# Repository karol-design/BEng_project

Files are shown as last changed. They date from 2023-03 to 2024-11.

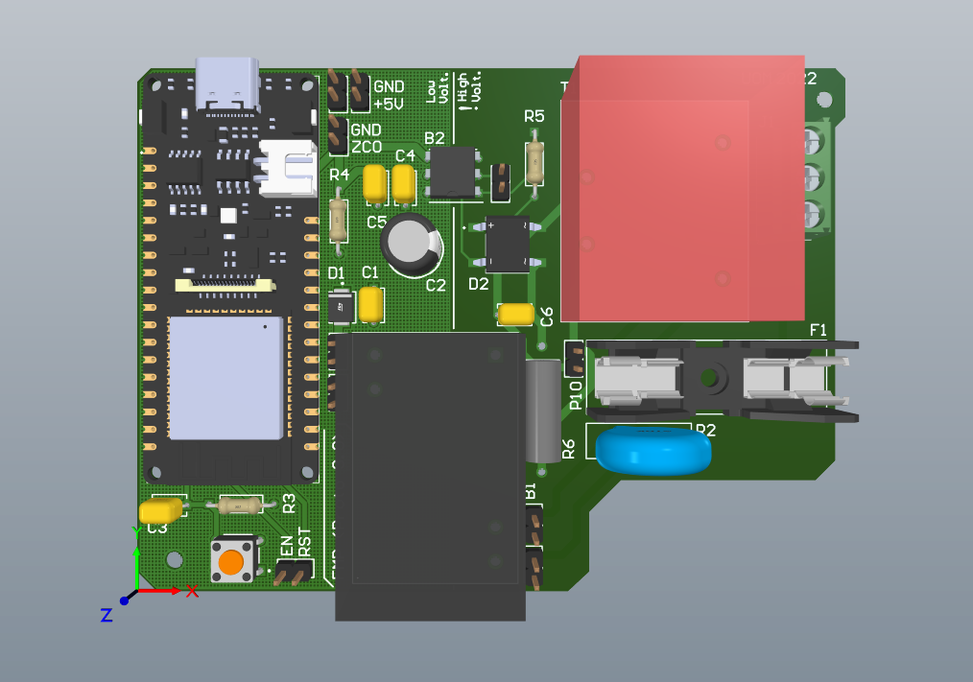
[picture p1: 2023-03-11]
board-design/FMP_Proto_4.0/Project Outputs for FMP_Proto_4.0/Proto4.0_3D.png

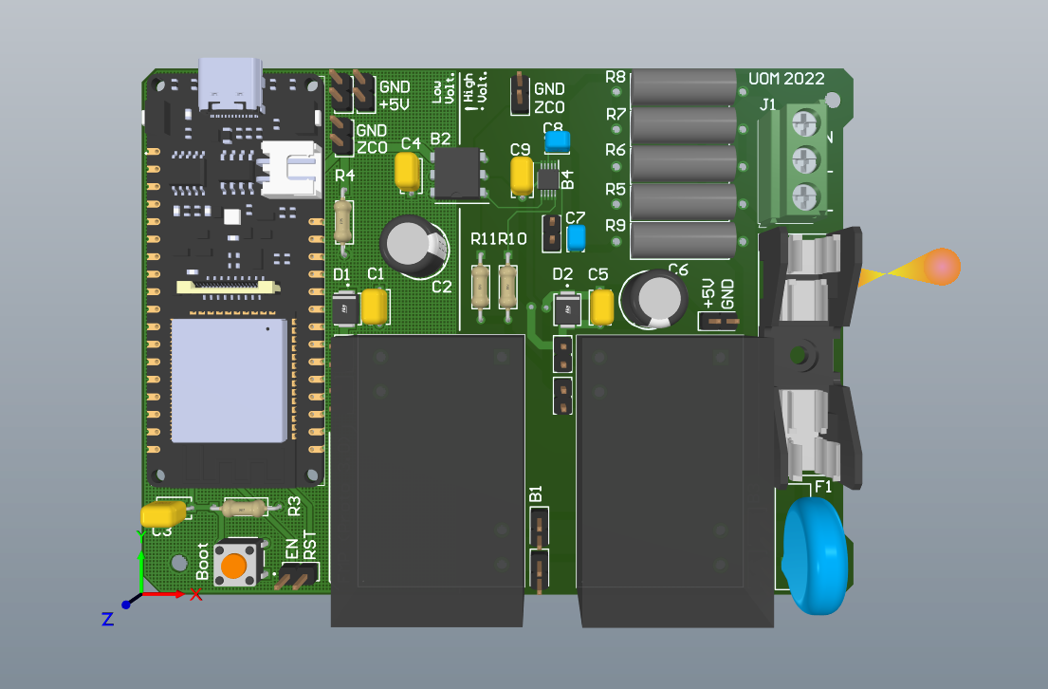
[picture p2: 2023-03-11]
board-design/FMP_Proto_3.0/Project Outputs for FMP_Proto_3.0/Proto3.0_3D.png

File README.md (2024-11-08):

HertzNet Logo
## HertzNet | High-accuracy Wireless Mains Frequency Measurement System
BEng 3rd Year Individual Project | University of Manchester

### CI Workflow results

 

## About 
HertzNet is a system for measuring mains (utility/line) frequency in different locations and aggregating collected data.

The aim of this project was to design and build a system for real-time mains frequency monitoring,
consisting of a low-price plug-in devices with wireless communication, capable of measuring and
uploading accurate and high-resolution frequency data and a web interface which aggregates that
data and makes it searchable and well-presented. 

## Directories
- /board-design - Altium Design files, i.e. Schematics, PCB layouts and 3D models of current and previous versions of the HertzNet Measurement Unit
- /board-fw - Firmware for ESP32-WROOM-32E MCU which controls the HertzNet Measurement Unit
- /cloud-scripts - MATLAB script(s) for the HeartzNet's ThingsSpeak channel

## Contributing (Firmware)
Commit to the main only the code that compile without any warnings or errors.
To test, compile or flash the code use ESP-IDF 4.4

### HertzNet Proto 3.0
3D Model for Proto 3.0

<center>Figure 1. - 3D Model for Proto 3.0</center>

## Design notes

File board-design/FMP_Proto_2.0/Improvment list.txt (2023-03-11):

Potential improvements circuit/PCB:
- more SMD components (resistors, capacitors, chips) and hence smaller size, better decoupling, closer to professional devices
- full galvanic isolation between mains voltage and logic sides (separate 5V power supply for the MAX IC)
- better physical isolation / differentiation between mains voltage and logic sides
- Live/Neutral swap protection, ideally in a form of a transformer with a bridge providing additional galvanic isolation and protection (very important, especially for EU plugs, which in most or all of the cases are unpolarised and there is no definite standard for the placement of Live / Neutral)
- Replace DFRobot ESP32 dev board with own circuit and ESP32 chip
- Replace the Earting wire (acts as a great victim of crosstalk from Live-Neutral loop, both capacitive and inductive crosstalk, if not connected to earth)
- Add Live, Neutral, Boot SW, Project name etc. labels on the PCB

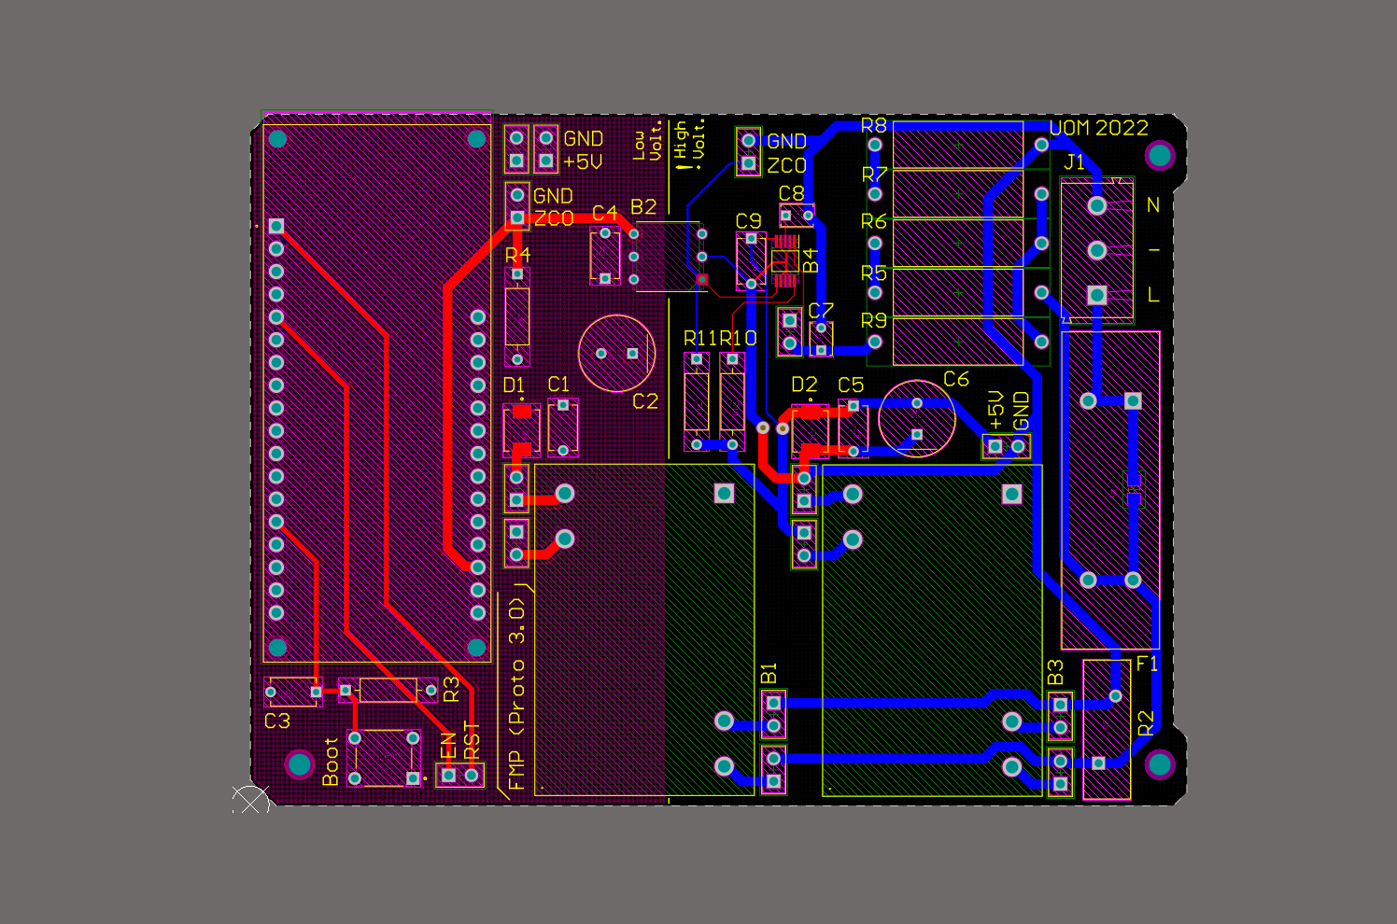
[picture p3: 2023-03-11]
board-design/FMP_Proto_3.0/Project Outputs for FMP_Proto_3.0/Proto3.0_PCB.png

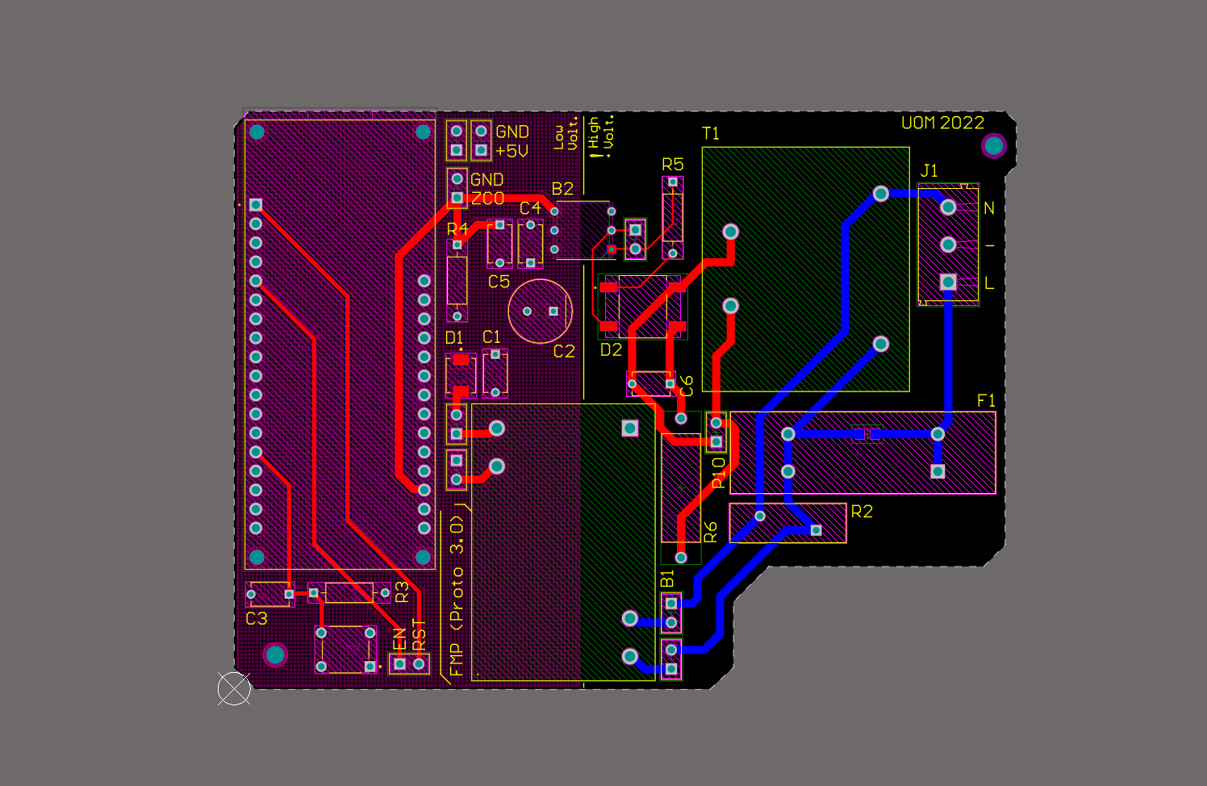
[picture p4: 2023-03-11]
board-design/FMP_Proto_4.0/Project Outputs for FMP_Proto_4.0/Proto4.0_PCB.png

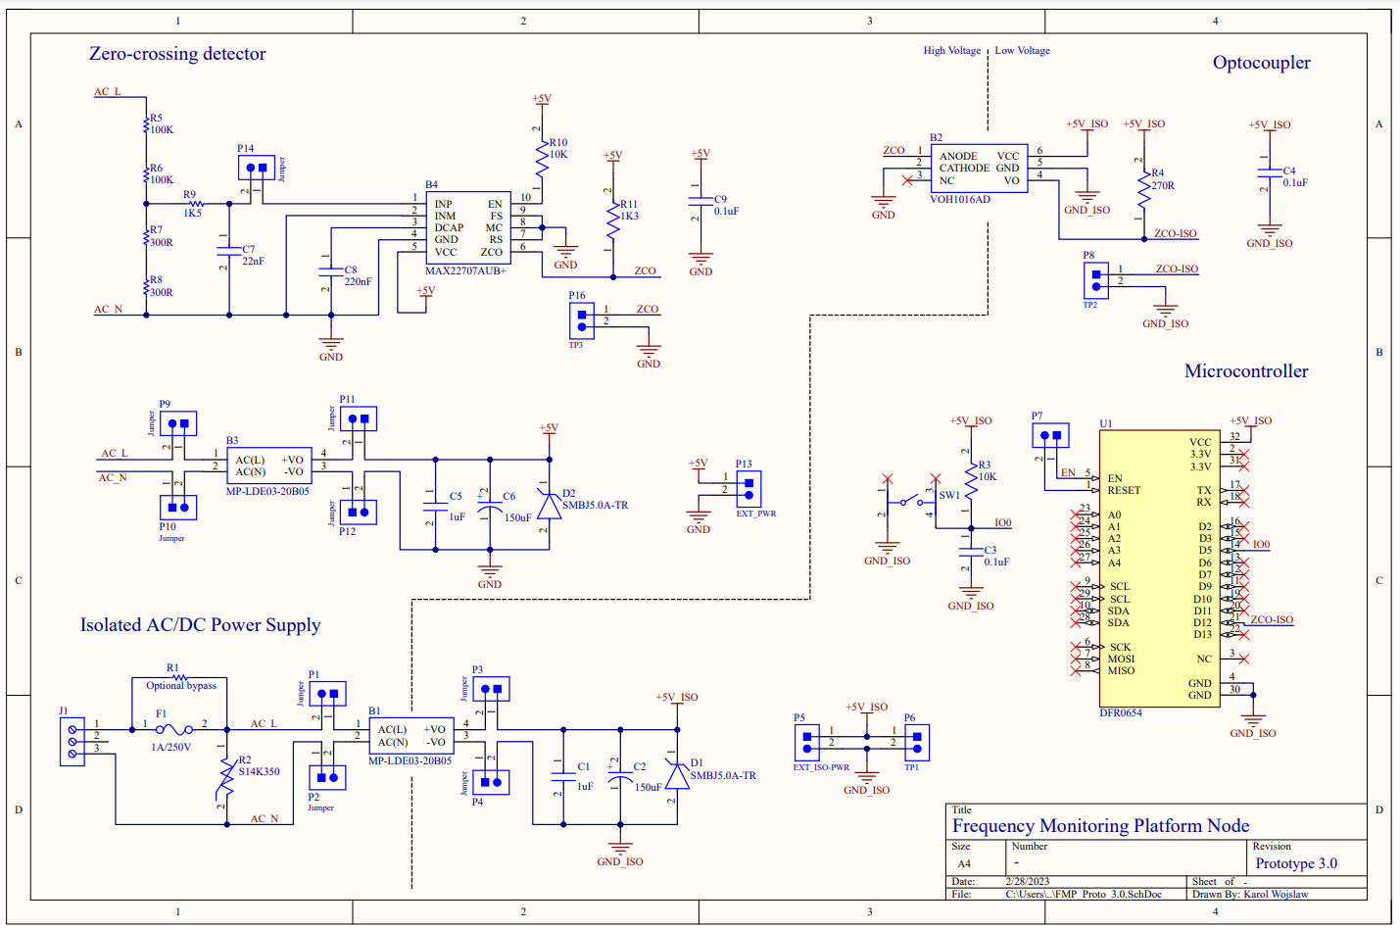
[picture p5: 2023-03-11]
board-design/FMP_Proto_3.0/Project Outputs for FMP_Proto_3.0/Proto3.0_SCH.png

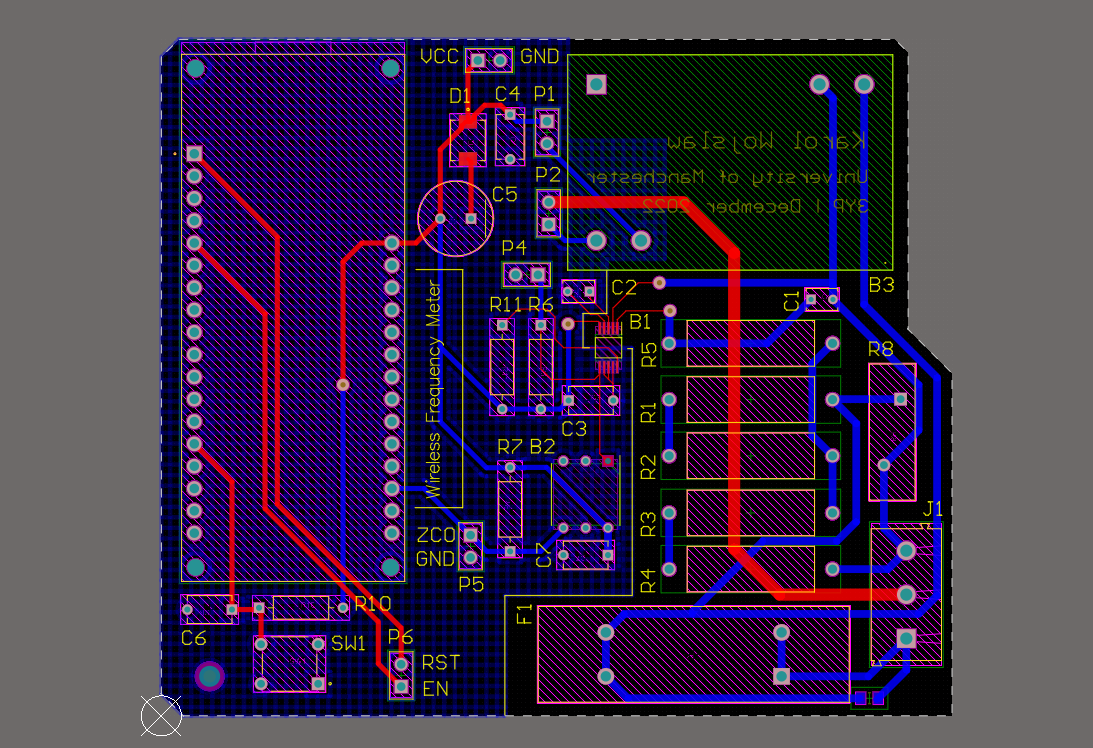
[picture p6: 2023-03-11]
board-design/FMP_Proto_2.0/Project Outputs for MFMS_Node/Proto2.0_PCB.png

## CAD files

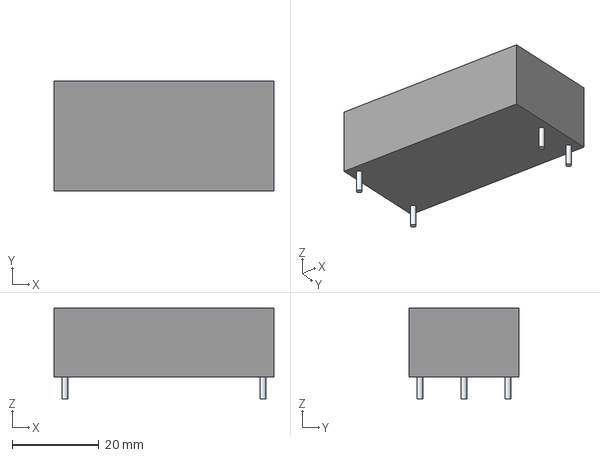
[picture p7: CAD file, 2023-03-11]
board-design/FMP_Proto_2.0/ECAD_models/MP-LDE03-20B05/MP-LDE06-20B24.stp
50.8 x 25.4 x 21.0 mm
Leads

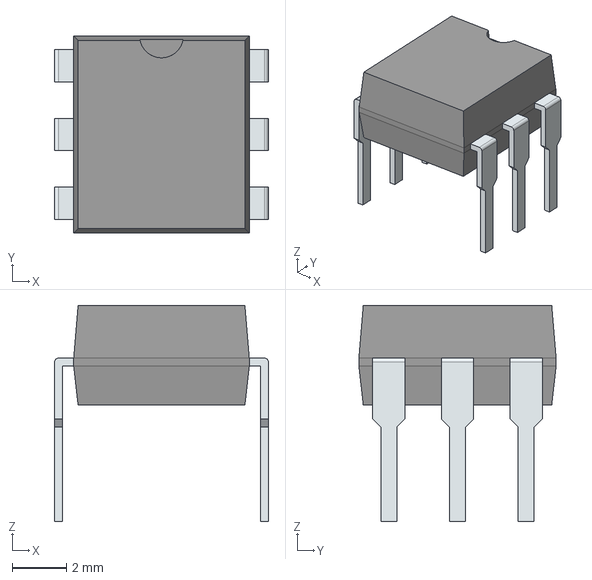
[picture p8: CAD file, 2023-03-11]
board-design/FMP_Proto_2.0/ECAD_models/VOH1016AD/VOH1016AD.stp
7.92 x 7.30 x 8.00 mm
PinsArrayLR

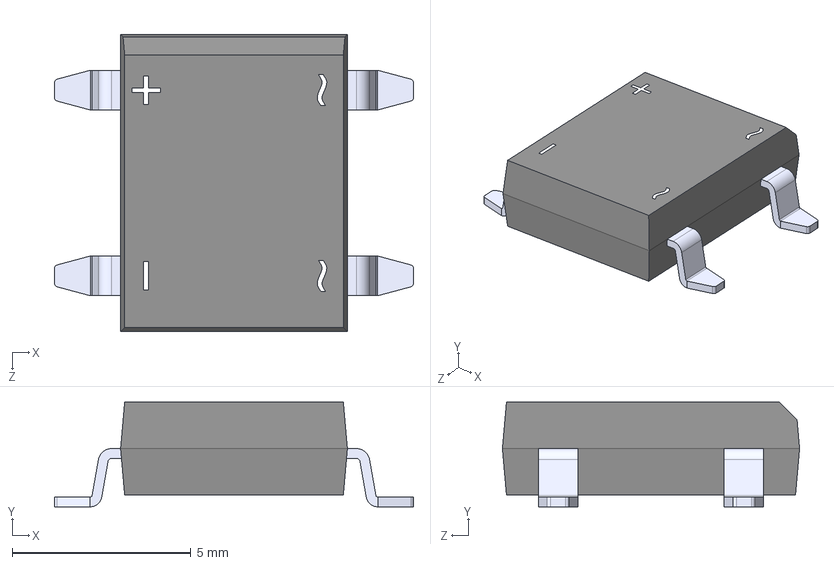
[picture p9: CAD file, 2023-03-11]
board-design/FMP_Proto_4.0/ECAD_models/DBLS106G/DBLS106G.STEP
10.1 x 2.93 x 8.32 mm

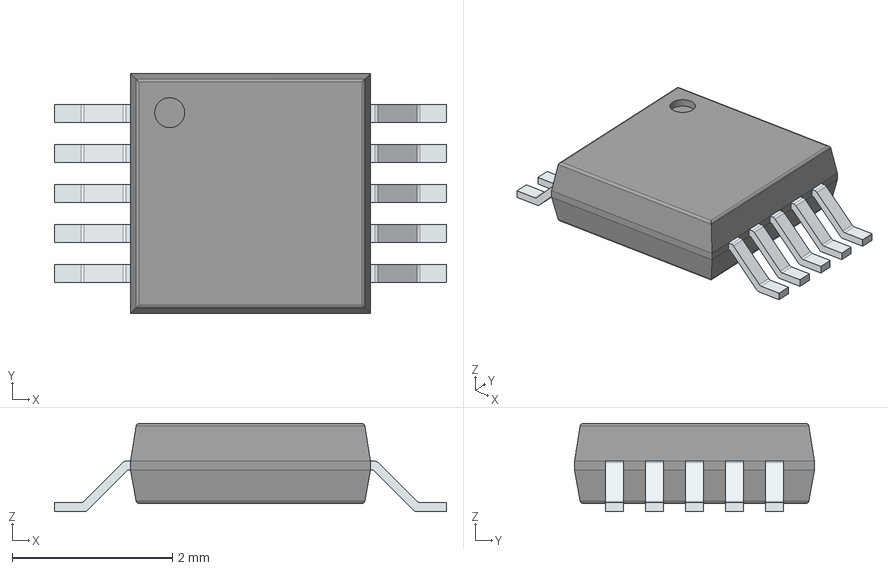
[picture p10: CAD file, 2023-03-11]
board-design/FMP_Proto_2.0/ECAD_models/MAX22707AUB+/MAX22707AUB+.stp
4.90 x 3.00 x 1.10 mm
PinsArrayLR

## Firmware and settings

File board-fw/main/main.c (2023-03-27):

/**
 * @file    main.c
 * @brief   Main application file
 * @author  Karol Wojslaw (karol.wojslaw@student.manchester.ac.uk)
 */

#include <stdio.h>
#include <stdlib.h>
#include <sys/time.h>

#include "f_measurement.h"
#include "freertos/FreeRTOS.h"
#include "mqtt_drv.h"
#include "nvs_flash.h"
#include "systime.h"
#include "wifi_drv.h"
#include "ws2812_drv.h"

#define TAG "app"

void app_main(void) {
    ESP_ERROR_CHECK(ws2812_drv_init());
    ESP_ERROR_CHECK(ws2812_drv_startup_animation(255));
    esp_err_t err = ESP_OK;
    mqtt_payload_t payload;  // MQTT Payload structure

    err = nvs_flash_init();  // Initialize NVS
    if (err == ESP_ERR_NVS_NO_FREE_PAGES || err == ESP_ERR_NVS_NEW_VERSION_FOUND) {
        ESP_ERROR_CHECK(nvs_flash_erase());  // Erase NVS flash memory
        err = nvs_flash_init();              // And try initialising it again
    }

    ESP_ERROR_CHECK(ws2812_drv_set_color(10, 10, 100, 60));
    ESP_ERROR_CHECK(wifi_drv_init());        // Initialise WiFi
    while (wifi_drv_connected() == false) {  // Wait for the device to connect to the AP
    }
    ESP_LOGI(TAG, "WiFi RSSI: %d", wifi_drv_get_rssi());
    ESP_ERROR_CHECK(ws2812_drv_set_color(10, 10, 100, 255));
    vTaskDelay(500 / portTICK_PERIOD_MS);

    ESP_ERROR_CHECK(ws2812_drv_set_color(50, 100, 10, 60));
    ESP_ERROR_CHECK(systime_synchronise());  // Synchronise system time using SNTP
    systime_log();                           // Print synchronised time
    ESP_ERROR_CHECK(ws2812_drv_set_color(50, 100, 10, 255));
    vTaskDelay(500 / portTICK_PERIOD_MS);
    ESP_ERROR_CHECK(ws2812_drv_set_color(0, 0, 0, 255));

    ESP_ERROR_CHECK(mqtt_drv_init());       // Initialise MQTT
    while (mqtt_drv_connected() != true) {  // Wait for the device to connect to the MQTT broker
    }

    ESP_ERROR_CHECK(f_measurement_init(ZCO_PIN));  // Initialise frequency measurement

#ifdef SYS_SELF_TEST
    ESP_LOGW(TAG, "-------- Start frequency measurement test --------\n");
    ESP_ERROR_CHECK(f_measurement_test(TEST_PIN));  // Initialise ZCO simulation
#endif

    /**** Infinite measure - upload loop ****/
    int64_t n = 0;
    while (true) {
        if (wifi_drv_fault() == true || mqtt_drv_connected() == false) {
            ESP_LOGE(TAG, "WiFi drv fault: %d || MQTT drv connected: %d", wifi_drv_fault(), mqtt_drv_connected());
            esp_restart();  // Reboot the microcontroller
        }
        f_measurement_t meas = f_measurement_get_val();       // Read frequency and timestamp
        payload.d[n % MQTT_MEAS_PER_BURST].f_hz = meas.freq;  // Copy the frequency value to payload
        payload.d[n % MQTT_MEAS_PER_BURST].t_ms = meas.time;  // Copy the timestamp to payload

        if (payload.d[n % MQTT_MEAS_PER_BURST].f_hz != -1.0) {  // Check if a new value was available
            if (((n + 1) % MQTT_MEAS_PER_BURST) == 0) {         // Send MQTT_MEAS_PER_BURST new datapoints through MQTT
                ESP_LOGD(TAG, "Sending %d new data points to the MQTT queue", MQTT_MEAS_PER_BURST);
                ESP_ERROR_CHECK(mqtt_drv_queue_send(payload, sizeof(payload)));
                ESP_ERROR_CHECK(ws2812_drv_set_color(0, 250, 10, 255));
                vTaskDelay(60 / portTICK_PERIOD_MS);
                ESP_ERROR_CHECK(ws2812_drv_set_color(0, 0, 0, 255));
            }
            n++;  // Increment data point number
        }
    }
}

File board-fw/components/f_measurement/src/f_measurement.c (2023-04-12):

/**
 * @file    f_measurement.c
 * @brief   Initialising interrupt, handling the ISR events via a seperate task, calculating the frequency
 * @author  Karol Wojslaw (karol.wojslaw@student.manchester.ac.uk)
 */

#include "f_measurement.h"

#include "systime.h"
#include "timer_drv.h"

#define TAG "f_measurement"
#define INCLUDE_vTaskSuspend 1

static xQueueHandle isr_count_queue = NULL;      // Queu for sending measured time
static xQueueHandle f_measurement_queue = NULL;  // Queu for sending measurement structs

static TaskHandle_t pxMeasurementTask = NULL;  // Task handle for f_measurement task

/**
 * @brief Interrupt Service Routine Handler
 */
static void IRAM_ATTR isr_handler(void *arg) {
    static uint64_t isr_count_total = 0;  // Number of timer ticks since timer init
    static uint64_t isr_pulses = 0;       // Number of interrupt pulses (isr calls)
    static uint64_t isr_count = 0;        // Number of timer ticks since last reading

    if (isr_pulses == 1) {
        isr_count_total = drv_timer_get_count_isr();  // Reset the isr_count_total with the first pulse
    }

    if ((isr_pulses % PULSES_PER_MEAS) == 0) {                    // Every PULSES_PER_MEAS
        isr_count = drv_timer_get_count_isr() - isr_count_total;  // Calc timer ticks since last reading
        isr_count_total = drv_timer_get_count_isr();
        xQueueSendFromISR(isr_count_queue, &isr_count, NULL);  // Send frequency value to the queue
        vTaskResume(pxMeasurementTask);
    }

    isr_pulses++;  // Increment pulses count each time ISR is executed
}

/**
 * @brief Frequency measurement task responsible for timestamping and queueing measurements
 */
static void f_measurement_task(void *param) {
    while (true) {
        struct timeval time;          // Struct to hold current system time
        uint64_t count;
        f_measurement_t meas = {.freq = -1.0, .time = 0};  // Initialise measurement struct as invalid

        if (xQueueReceive(isr_count_queue, &count, portMAX_DELAY) == pdTRUE) {
            gettimeofday(&time, NULL);  // Copy current sys time to sys_time struct and calc time in ms
            meas.time = (((uint64_t)time.tv_sec * 1000) + ((uint64_t)time.tv_usec / 1000));

            // Timer f: 40 MHz, PULSES_PER_MEAS pulses
            meas.freq = (float)(((40 * 1000000 * (uint64_t)PULSES_PER_MEAS)) / (float)count);
            meas.freq = (meas.freq > 51.0) ? 51.0 : meas.freq;  // Set the upper limit to 51 Hz
            meas.freq = (meas.freq < 49.0) ? 49.0 : meas.freq;  // Set the lowee limit to 49 Hz

            xQueueSend(f_measurement_queue, &meas, (TickType_t)0);
        }

        vTaskSuspend(NULL);  // Suspend itself
    }
}

/**
 * @brief Read measured frequency if a new value is available
 * @return Frequency or -1 if no new value is available
 */
f_measurement_t f_measurement_get_val() {
    f_measurement_t meas = {.freq = -1.0, .time = 0};  // Initialise measurement struct as invalid

    if (xQueueReceive(f_measurement_queue, &meas, portMAX_DELAY) == pdTRUE) {
        ESP_LOGI(TAG, "New measurement: %.3lf Hz | %llu ms", meas.freq, meas.time);
    }

    return meas;
}

/**
 * @brief Interrupt GPIO pin configuration
 * @param gpio_input_pin_sel bit mask of the pin to be used for an interrupt
 * @return Error code
 */
static esp_err_t intr_gpio_config(uint64_t gpio_input_pin_sel) {
    gpio_config_t io_conf = {
        // GPIO Configuration structure
        .pin_bit_mask = gpio_input_pin_sel,  // Bit mask of the pin to be used for an interrupt
        .mode = GPIO_MODE_INPUT,             // Set as input mode
        .pull_up_en = 1,                     // Enable pull-up mode
        .intr_type = GPIO_INTR_POSEDGE       // Interrupt of rising edge
    };

    // Configure GPIO with the given settings
    ESP_RETURN_ON_ERROR(gpio_config(&io_conf), TAG, "Failed to configure GPIO");
    ESP_LOGI(TAG, "INTR GPIO Configured");
    return ESP_OK;
}

/**
 * @brief Initialise frequency measurement: Interrupt (GPIO, Task, Que, ISR) and Timer
 * @param gpio_interrupt pin to be used for the interrupt
 * @return Error code
 */
esp_err_t f_measurement_init(uint64_t gpio_interrupt) {
    ESP_RETURN_ON_ERROR(drv_timer_init(), TAG, "Timer driver initialisation failed");

    uint64_t gpio_input_pin_select = (1ULL << gpio_interrupt);
    // Initialise gpio for the interrupt
    ESP_RETURN_ON_ERROR(intr_gpio_config(gpio_input_pin_select), TAG, "Failed to initialise GPIO Interrupt");

    // Create a queue for one burst of isr count values and measurements (f & time) structs
    isr_count_queue = xQueueCreate(MQTT_MEAS_PER_BURST, sizeof(uint64_t));
    f_measurement_queue = xQueueCreate(MQTT_MEAS_PER_BURST, sizeof(f_measurement_t));

    // Install gpio isr service
    ESP_RETURN_ON_ERROR(gpio_install_isr_service(ESP_INTR_FLAG_DEFAULT), TAG, "Failed to install ISR Service");
    // Hook isr handler for specific gpio pin
    ESP_RETURN_ON_ERROR(gpio_isr_handler_add(gpio_interrupt, isr_handler, NULL), TAG, "Failed to add ISR Handler");

    // Start frequency measurement task
    xTaskCreate(f_measurement_task, "f_measurement_task", 2048, NULL, (configMAX_PRIORITIES - 1), &pxMeasurementTask);
    ESP_LOGI(TAG, "Frequency measurement task created");

    ESP_LOGI(TAG, "ISR Service installed, handler added, interrupt task created");
    return ESP_OK;
}
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

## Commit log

2022-10-26 Create interrupt test project
2022-10-26 Update interrupt project
2022-10-26 Update interrupt component
2022-10-26 Update interrupt_drv component
2022-11-13 Update timers_drv
2023-02-08 Add WiFi driver
2023-02-15 Timer refactoring
2023-03-11 Board design files added
    [DBLS106G.STEP, DBLS106G.SchLib, DFR0654.SchLib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]
2023-03-15 Add WS2812 driver component
2023-03-22 Review, debug and refactor WS2812 driver
2023-03-26 Fix WiFi can't-connect loop and improve system resilience to AP fults
    [main.c]
2023-03-27 Replace ESP_ERROR_CHECK with ESP_RETURN_ON_ERROR
    [f_measurement.c]
2023-03-27 Add a reboot on MQTT Disconnected event
    [main.c]
2023-03-27 Add Error log before rebooting
    [main.c]
2023-03-27 Add f_measurement task and move timestamping
    Fixed the problem with unpredictable occasional reboots
    [f_measurement.c]
2023-04-12 Update design files
    [FMP_Proto_3.0.SchDoc]
